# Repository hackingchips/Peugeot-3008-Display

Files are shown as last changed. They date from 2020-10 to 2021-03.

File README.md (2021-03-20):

## Repairing Peugeot 3008 display. ##

This repository is about changing the LCD crystal of my Peugeot 3008 multifunction display.

If you want more information go the following links:

* http://www.hackingchips.com/2020/09/reparacion-de-display-peugeot-3008.html
* http://www.hackingchips.com/2020/09/reparacion-de-display-peugeot-3008_22.html
* http://www.hackingchips.com/2020/09/reparacion-de-display-peugeot-3008_23.html
* http://www.hackingchips.com/2020/09/reparacion-de-display-peugeot-3008_25.html
* http://www.hackingchips.com/2020/09/reparacion-de-display-peugeot-3008_26.html
* http://www.hackingchips.com/2020/10/reparacion-de-display-peugeot-3008.html

### Repository. ###
* Docs: Datasheets and notes.
* Firmware/PeugeotDisplay4245: Firmware for Cypress PSoC CY8C4245 (PSoC Creator 4.3 project).
* Hardware/PeugeotTypeCDisplayHack: Kicad project (schematic & pcb board).
* Mechanical: 3D models.
* NewestArchives_xxx_date_xxx: Latest binary & docs.

#### Thanks to Peter Pinter ([morcibacsi]). His project PSAWifiDisplayControl (https://github.com/morcibacsi/PSAWifiDisplayControl) saved me a lot of work. ####

[morcibacsi]: https://github.com/morcibacsi

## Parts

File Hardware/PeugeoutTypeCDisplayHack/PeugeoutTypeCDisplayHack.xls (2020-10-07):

Source | C:\Users\Jesus\Desktop\display_coche\LCD_Substitute\Hardware\PeugeoutTypeCDisplayHack\PeugeoutTypeCDisplayHack.sch
Kicad Rev | Eeschema (5.1.6)-1
Generated Date | 24/09/2020 17:53:35
Title | Peugeot Type C Display Hack
Company | Hackingchips.com
Revision | 1
Date Issue | 2020-09-18
Comment | (C) Jesús Rodríguez Cacabelos
Reference | Value | Library | Library Ref
J3 | ER-CON30HB-1 | PeugeotTypeCDisplayHack | ER-CON30HB-1
C12 | 4u7 | PeugeotTypeCDisplayHack | CP_Small
C13 | 4u7 | PeugeotTypeCDisplayHack | CP_Small
C11 | 100nF | PeugeotTypeCDisplayHack | C_Small
C8 | 10uF | PeugeotTypeCDisplayHack | CP_Small
C9 | 100nF | PeugeotTypeCDisplayHack | C_Small
U2 | CY8C4245AXI-483 | PeugeotTypeCDisplayHack | CY8C4245AXI-483
C6 | 10nF | PeugeotTypeCDisplayHack | C
C7 | 100nF | PeugeotTypeCDisplayHack | C
C5 | 1uF/25 | PeugeotTypeCDisplayHack | C
C10 | 100nF | PeugeotTypeCDisplayHack | C_Small
R1 | 4K7 | PeugeotTypeCDisplayHack | R_US
R10 | 10M | PeugeotTypeCDisplayHack | R_US
C3 | 10uF | PeugeotTypeCDisplayHack | CP
C1 | 10uF | PeugeotTypeCDisplayHack | CP
C4 | 100nF | PeugeotTypeCDisplayHack | C
C2 | 100nf | PeugeotTypeCDisplayHack | C
R2 | 1K | PeugeotTypeCDisplayHack | R_US
R3 | 1K | PeugeotTypeCDisplayHack | R_US
R4 | 1K | PeugeotTypeCDisplayHack | R_US
R5 | 1K | PeugeotTypeCDisplayHack | R_US
R6 | 2K | PeugeotTypeCDisplayHack | R_US
R8 | 2K | PeugeotTypeCDisplayHack | R_US
R7 | 2K | PeugeotTypeCDisplayHack | R_US
R9 | 2K | PeugeotTypeCDisplayHack | R_US
J1 | PeugeotPCBConnector | PeugeotTypeCDisplayHack | PeugeotPCBConnector
U1 | LM1117-3.3 | PeugeotTypeCDisplayHack | LM1117-3.3
J2 | Conn_01x05 | PeugeotTypeCDisplayHack | Conn_01x05
J4 | Backlight | PeugeotTypeCDisplayHack | Conn_01x02
R11 | ??? | PeugeotTypeCDisplayHack | R_US
S2 | F.Use | PeugeotTypeCDisplayHack | Conn_01x02
S1 | F.Use | PeugeotTypeCDisplayHack | Conn_01x02

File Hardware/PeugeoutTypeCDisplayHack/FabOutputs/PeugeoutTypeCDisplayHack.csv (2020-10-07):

Id | Identificador | Empaquetado | Cantidad | Identificación | Suministrador y ref
1 | R11 | R_1206_3216Metric_Pad1.42x1.75mm_HandSolder | 1 | ???
2 | J4 | PinHeader_1x02_P2.00mm_Vertical | 1 | Backlight
3 | R1 | R_0805_2012Metric_Pad1.15x1.40mm_HandSolder | 1 | 4K7
4 | J2 | PinHeader_1x05_P1.27mm_Vertical | 1 | Conn_01x05
5 | R10 | R_0805_2012Metric_Pad1.15x1.40mm_HandSolder | 1 | 10M
6 | R9,R8,R7,R6 | R_0805_2012Metric_Pad1.15x1.40mm_HandSolder | 4 | 2K
7 | R5,R4,R3,R2 | R_0805_2012Metric_Pad1.15x1.40mm_HandSolder | 4 | 1K
8 | C13,C12 | C_0805_2012Metric_Pad1.15x1.40mm_HandSolder | 2 | 4u7
9 | C11,C10,C9,C7,C4 | C_0805_2012Metric_Pad1.15x1.40mm_HandSolder | 5 | 100nF
10 | C8,C3,C1 | C_0805_2012Metric_Pad1.15x1.40mm_HandSolder | 3 | 10uF
11 | C6 | C_0805_2012Metric_Pad1.15x1.40mm_HandSolder | 1 | 10nF
12 | C5 | C_0805_2012Metric_Pad1.15x1.40mm_HandSolder | 1 | 1uF/25
13 | C2 | C_0805_2012Metric_Pad1.15x1.40mm_HandSolder | 1 | 100nf
14 | U1 | SOT-223-3_TabPin2 | 1 | LM1117-3.3
15 | J1 | PeugeotPCBConnector | 1 | PeugeotPCBConnector
16 | U2 | TQFP-44_10x10mm_P0.8mm | 1 | CY8C4245AXI-483
17 | J3 | ER-CON30HB-1 | 1 | ER-CON30HB-1

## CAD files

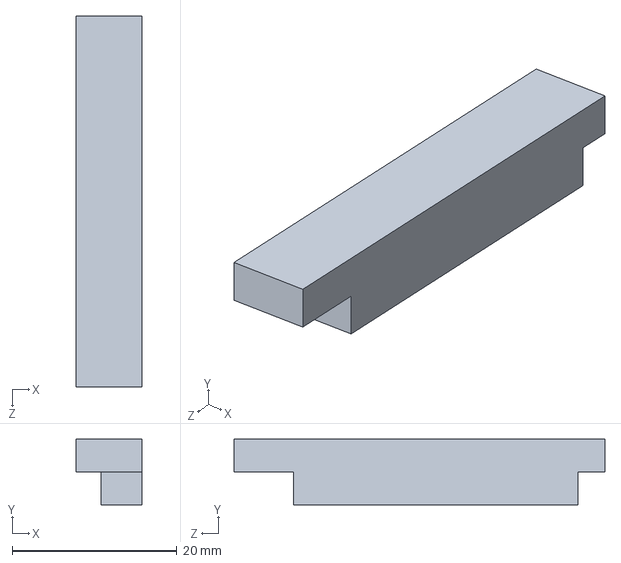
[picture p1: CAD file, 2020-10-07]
Mechanical/Sup_Left.SLDPRT
8.00 x 8.00 x 45.0 mm

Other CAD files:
Mechanical/Sup_Right.SLDPRT
Mechanical/Sup_Left.STL
Mechanical/Sup_Right.STL

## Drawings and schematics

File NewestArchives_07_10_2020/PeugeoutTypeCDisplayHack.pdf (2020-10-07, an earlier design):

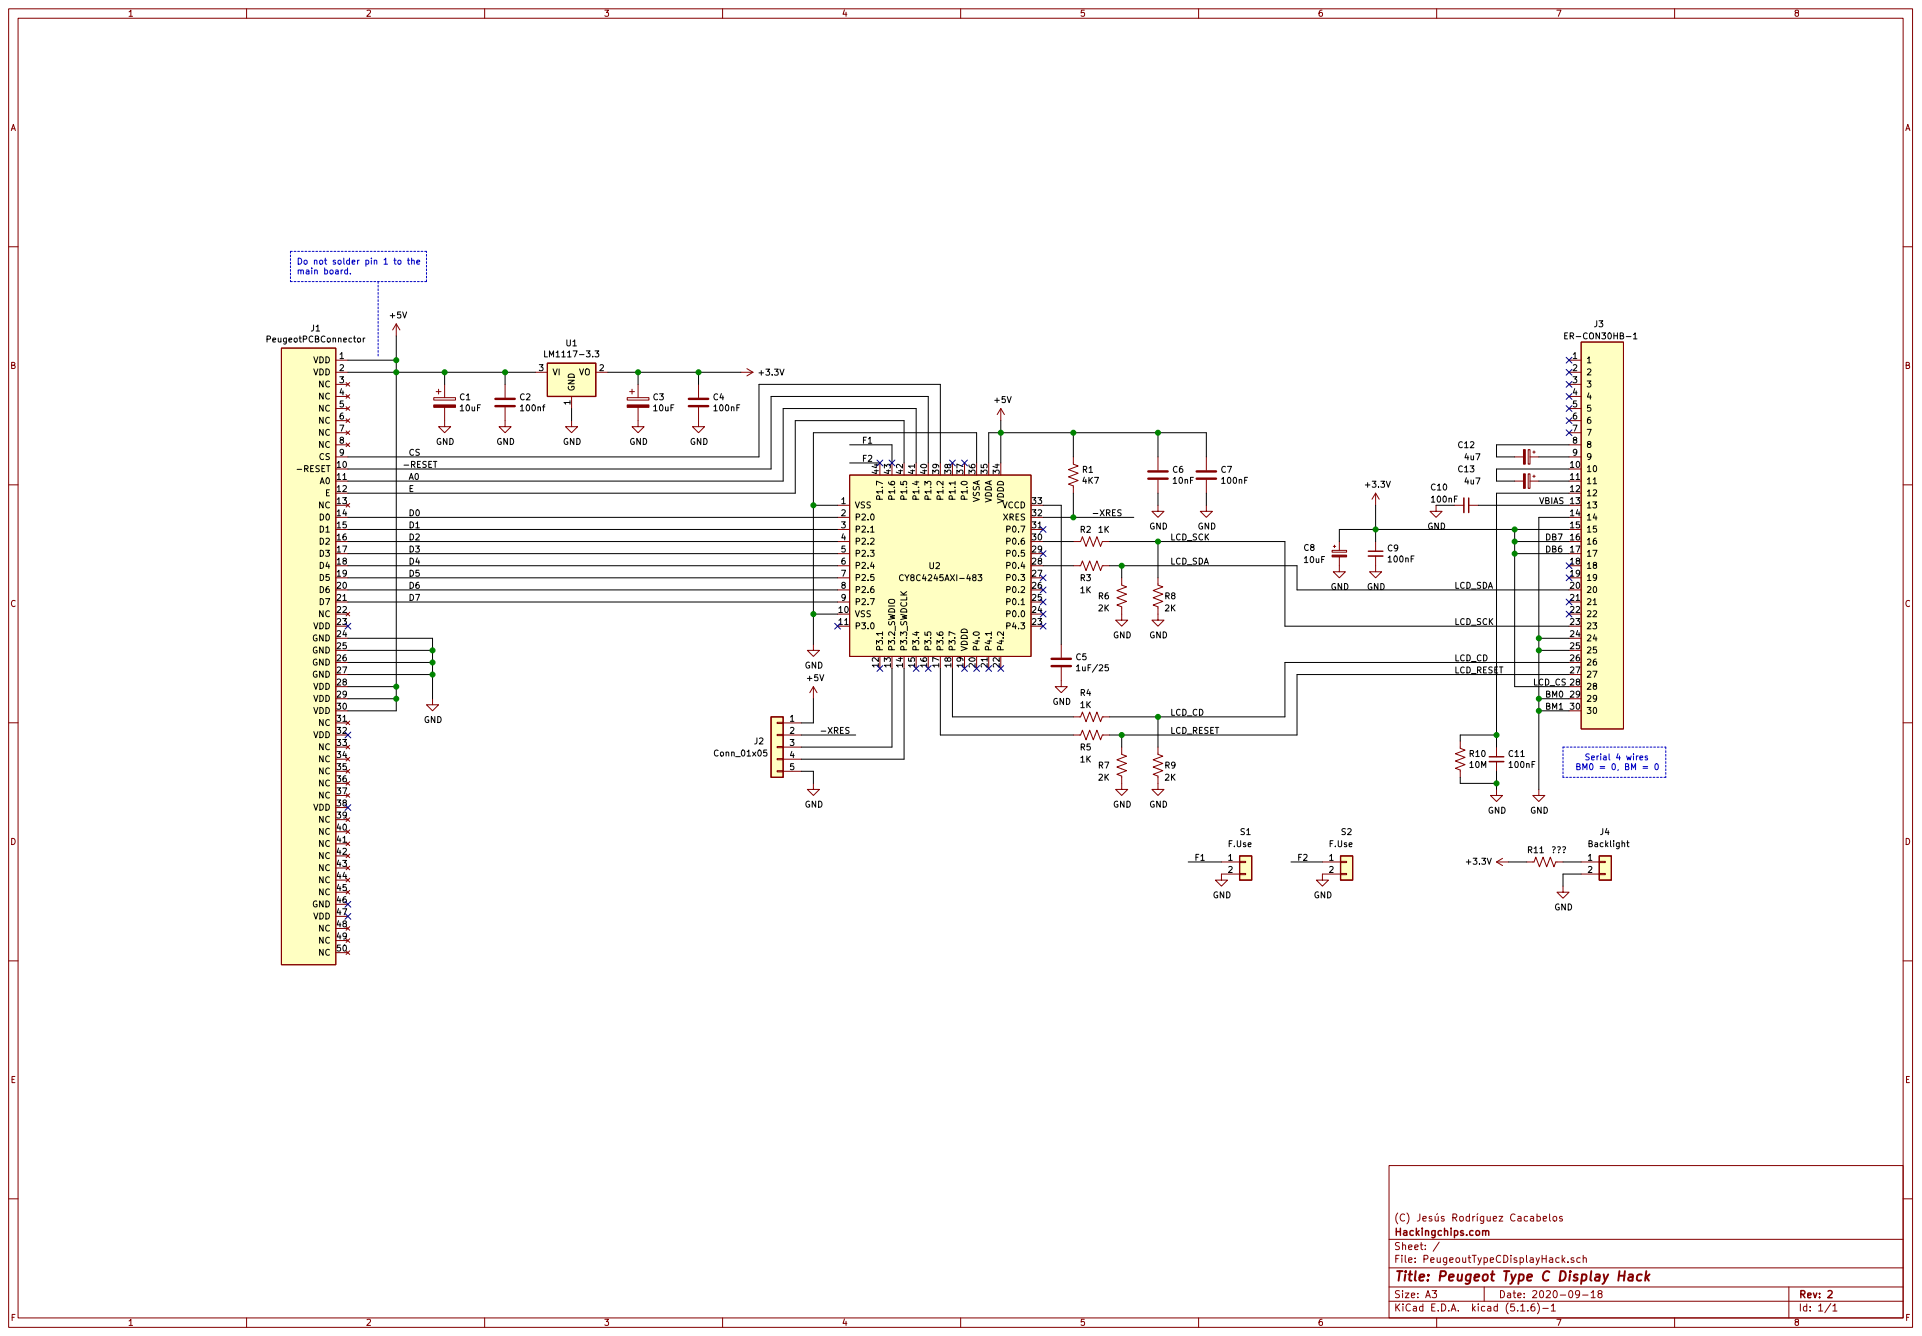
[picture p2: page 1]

A0ED1 Do not solder pin 1 to the main board.

LCD_RESET

LCD_CS

(C) Jesús Rodríguez Cacabelos
File: PeugeoutTypeCDisplayHack.sch Sheet: / Hackingchips.com

Id: 1/1 Title: Peugeot Type C Display Hack

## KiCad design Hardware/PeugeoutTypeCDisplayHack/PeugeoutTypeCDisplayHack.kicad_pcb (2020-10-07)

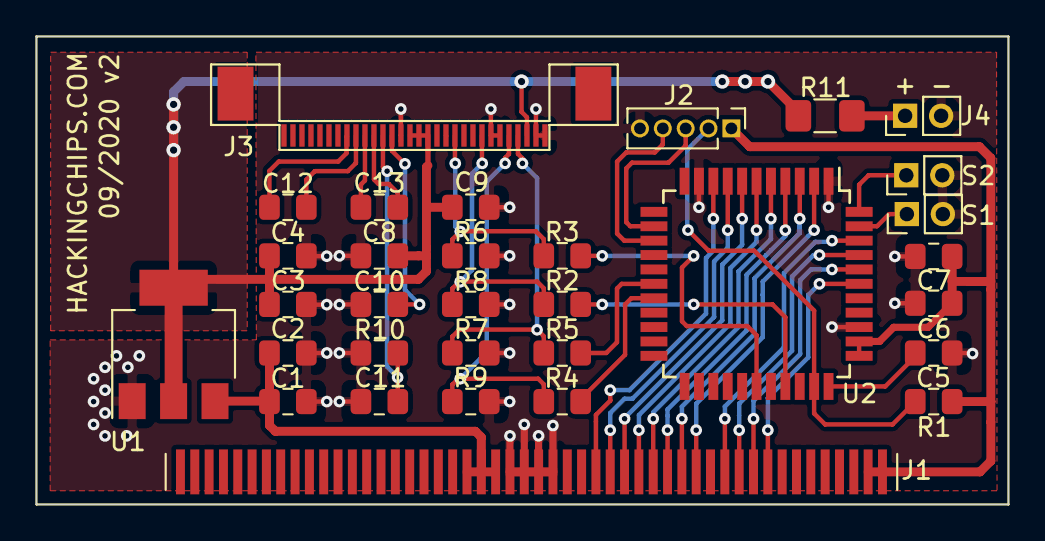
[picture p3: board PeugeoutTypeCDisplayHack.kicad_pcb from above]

Board: 2 copper layers, 54.0 x 26.0 mm, 32 parts (0 on the bottom side), 36 nets.

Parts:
C1, C3, C8: 10uF; C_0805_2012Metric_Pad1.15x1.40mm_HandSolder
C2: 100nf; C_0805_2012Metric_Pad1.15x1.40mm_HandSolder
C4, C7, C9, C10, C11: 100nF; C_0805_2012Metric_Pad1.15x1.40mm_HandSolder
C5: 1uF/25; C_0805_2012Metric_Pad1.15x1.40mm_HandSolder
C6: 10nF; C_0805_2012Metric_Pad1.15x1.40mm_HandSolder
C12, C13: 4u7; C_0805_2012Metric_Pad1.15x1.40mm_HandSolder
J1: PeugeotPCBConnector
J2: Conn_01x05; PinHeader_1x05_P1.27mm_Vertical
J3: ER-CON30HB-1
J4: Backlight; PinHeader_1x02_P2.00mm_Vertical
R1: 4K7; R_0805_2012Metric_Pad1.15x1.40mm_HandSolder
R2, R3, R4, R5: 1K; R_0805_2012Metric_Pad1.15x1.40mm_HandSolder
R6, R7, R8, R9: 2K; R_0805_2012Metric_Pad1.15x1.40mm_HandSolder
R10: 10M; R_0805_2012Metric_Pad1.15x1.40mm_HandSolder
R11: ???; R_1206_3216Metric_Pad1.42x1.75mm_HandSolder
S1, S2: F.Use; PinHeader_1x02_P2.00mm_Vertical
U1: LM1117-3.3; SOT-223-3_TabPin2
U2: CY8C4245AXI-483; TQFP-44_10x10mm_P0.8mm

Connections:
+3V3: C3.1, C4.1, C8.1, C9.1, J3.15, J3.16, J3.17, J3.28, R11.2, U1.2
+5V: C1.1, C2.1, C6.1, C7.1, J1.1, J1.2, J1.28, J1.29, J1.30, J2.1, R1.1, U1.3, U2.34, U2.35
/-RESET: J1.10, U2.40
/-XRES: J2.2, R1.2, U2.32
/A0: J1.11, U2.41
/CS: J1.9, U2.39
/D0: J1.14, U2.2
/D1: J1.15, U2.3
/D2: J1.16, U2.4
/D3: J1.17, U2.5
/D4: J1.18, U2.6
/D5: J1.19, U2.7
/D6: J1.20, U2.8
/D7: J1.21, U2.9
/E: J1.12, U2.42
/F1: S1.1, U2.43
/F2: S2.1, U2.44
/LCD_CD: J3.26, R4.1, R9.1
/LCD_RESET: J3.27, R5.1, R7.1
/LCD_SCK: J3.23, R2.1, R8.1
/LCD_SDA: J3.20, R3.1, R6.1
/VBIAS: C10.1, J3.13
GND: C1.2, C2.2, C3.2, C4.2, C5.2, C6.2, C7.2, C8.2, C9.2, C10.2, C11.2, J1.24, J1.25, J1.26, J1.27, J2.5, J3.14, J3.24, J3.25, J3.29, J3.30, J4.2, R6.2, R7.2, R8.2, R9.2, R10.2, S1.2, S2.2, U1.1, U2.1, U2.10, U2.36
unnamed: C5.1, U2.33
unnamed: C11.1, J3.12, R10.1
unnamed: C12.1, J3.9
unnamed: C12.2, J3.8
unnamed: C13.1, J3.11
unnamed: C13.2, J3.10
unnamed: J2.3, U2.13
unnamed: J2.4, U2.14
unnamed: J4.1, R11.1
unnamed: R2.2, U2.30
unnamed: R3.2, U2.28
unnamed: R4.2, U2.18
unnamed: R5.2, U2.17

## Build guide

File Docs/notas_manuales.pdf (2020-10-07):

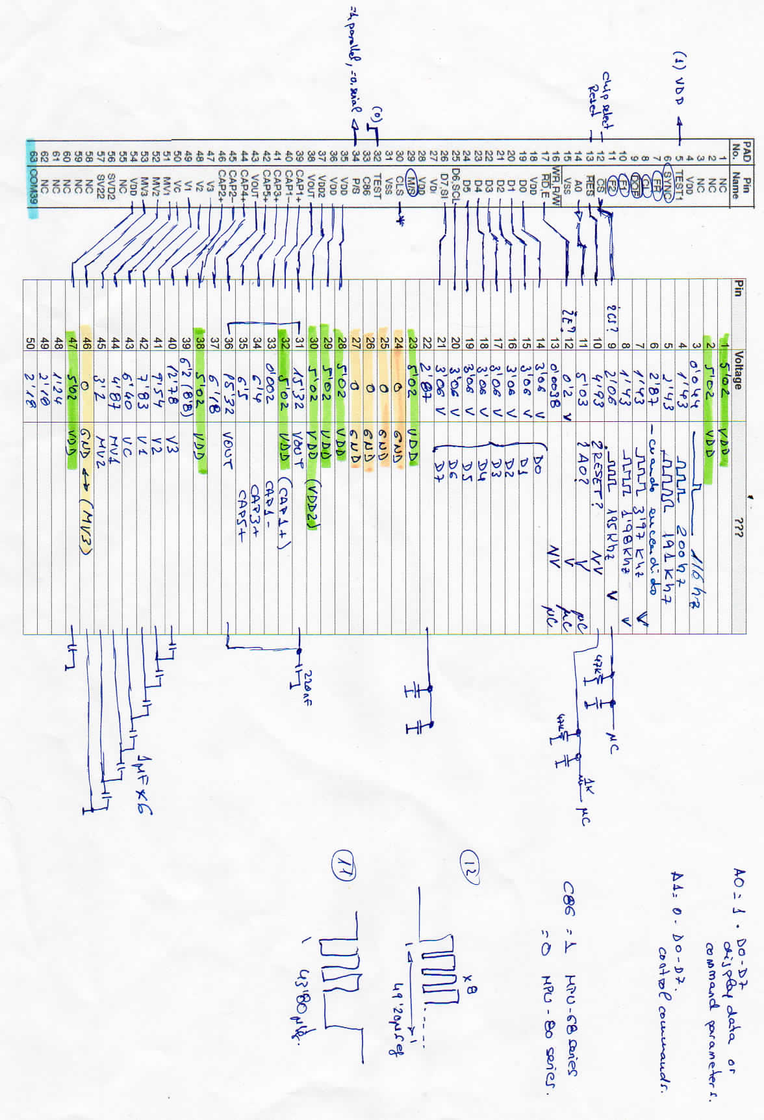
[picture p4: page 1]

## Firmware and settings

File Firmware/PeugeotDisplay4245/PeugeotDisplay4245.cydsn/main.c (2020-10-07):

/* ========================================
 *
 * Copyright YOUR COMPANY, THE YEAR
 * All Rights Reserved
 * UNPUBLISHED, LICENSED SOFTWARE.
 *
 * CONFIDENTIAL AND PROPRIETARY INFORMATION
 * WHICH IS THE PROPERTY OF your company.
 *
 * ========================================
*/
#include "project.h"
#include "UC1608.h"

//#define SERIAL_PORT_SEND_DATA
#define SERIAL_PORT_SEND_PROCCESSED

/* ************************************************************************* */
enum { IDLE, DATA0, DATA1, DATA2 } BUS_STATE;

volatile    uint8 bus_state = IDLE;

volatile    uint8 data_buffer[2000];
volatile    uint16 data_buffer_ptr = 0;

volatile    uint8 data_ready = 0;

volatile    uint8 enable_capture = 0;

volatile    uint8 combined_data = 0;
volatile    uint8 page_counter = 0;
volatile    uint8 column_counter = 0;
volatile    uint8 is_first_byte = 1;

volatile    uint8 display_set_normal = 0;
volatile    uint8 display_set_reverse = 0;

/* Interrupt prototypes */
CY_ISR_PROTO(ISR_Reset_Handler);
CY_ISR_PROTO(ISR_Capture);

void Uart_SendCommandString(uint8 command);

/* ************************************************************************* */


/* Manage interrupt from RESET. */
CY_ISR(ISR_Reset_Handler)
{
}

/* Manage interrupt for command capture. */
CY_ISR(ISR_Capture_Handler)
{
    uint8 a0_state = A0_Read();
    uint8 e_state = E_Read();
    
    uint8 bdata = IData_Port_Read();
    
    /* *** Waiting for command "data write". *** */
    if (bus_state == IDLE)
    {
        if ((e_state == 1) && (a0_state == 0))
        {
            if (bdata == 0b00011101)                                            // 0b00011101 = Display data write command.
            {
                page_counter = column_counter = data_buffer_ptr = 0;            // Initialize counters and buffer pointer.
                bus_state = DATA0;
            }
            
            if (bdata == 0b10100110) display_set_normal = 1;                    // Display normal.
            if (bdata == 0b10100111) display_set_reverse = 1;                   // Display reverse.
        }
    }
    /* *** First byte received is a dummy byte. We discard it. *** */
    else if (bus_state == DATA0) 
    {
        bus_state = DATA1;
    }
    /* *** Received even page byte. *** */
    else if (bus_state == DATA1)
    {

        if ((e_state == 0) && (a0_state == 1))
        {
            if ((page_counter < 16) && (column_counter < 240))                  // Data outside display is discarded.
            {
                combined_data = (bdata & 0b00000001) |                          // Isolate every low bit of every pixel and move them to the 
                                ((bdata & 0b00000100) >> 1) |                   // lower nibble of the final data byte.
                                ((bdata & 0b00010000) >> 2) |
                                ((bdata & 0b01000000) >> 3);
                                
                bus_state = DATA2;
            }
                            
            page_counter++;
            if (page_counter == 21) 
            {
                page_counter = 0; 
                column_counter++;
            }
        }
        else if ( e_state == 1 )
        {
            data_ready = 1;
            bus_state = IDLE;
            CyGlobalIntDisable;
        }

    }
    /* *** Received odd page byte. *** */
    else if (bus_state == DATA2)
    {
        if ((e_state == 0) && (a0_state == 1))
        {
            if ((page_counter < 16) && (column_counter < 240))                  // Data outside display is discarded.
            {
                combined_data = combined_data | ((bdata & 0b00000001) << 4) |   // Isolate every low bit of every pixel and move them to the
                                                ((bdata & 0b00000100) << 3) |   // higher nibble of the final data byte.
                                                ((bdata & 0b00010000) << 2) |   // Combine it with the previous lower nibble.
                                                ((bdata & 0b01000000) << 1);
                                                
                bus_state = DATA1;
                                                
                data_buffer[data_buffer_ptr] = combined_data;
                data_buffer_ptr++;
            }
                                            
            page_counter++;
            if (page_counter == 21) 
            {
                page_counter = 0; 
                column_counter++;
            }                                             
        }
        else if ( e_state == 1 )                                                
        {
            data_ready = 1;                                                     // All data has been received, converted to 1 byte 
            bus_state = IDLE;                                                   // monocrome and stored in buffer.
            CyGlobalIntDisable;                                                 // Set data_ready flag and disable interrupts.
        }
    }    
}

/* ************************************************************************* */

int main(void)
{
    uint8 page, column;
    
    /* Configure and enable interrupts. */
    ISR_Reset_StartEx(ISR_Reset_Handler);
    ISR_Capture_StartEx(ISR_Capture_Handler);
    //CyGlobalIntEnable;
    
    /* Init SPILCD. */
    SPILCD_Start();
    
    /* Initialize the display. */
    LCD_Init();
    LCD_Clear();     
          
    LCD_SetPageAddress(0);
    LCD_SetColumnAddress(0);    
    
    enable_capture = 1;
    CyGlobalIntEnable;    

    for(;;)
    {
  
        /* --------------------------------------------- */
        
        if (data_ready == 1)
        {
            LCD_SetPageAddress(0);
            LCD_SetColumnAddress(0);
        
            for (page = 0; page < 8; page++)
            {    
                for (column = 0; column < 240; column++)
                {
                
                    UC1608_Write_data(data_buffer[(column * 8) + page]);
                }
            }            
            
            if (enable_capture) CyGlobalIntEnable;
        }
        
        if (display_set_normal)
        {
            LCD_DisplayNormal();
            display_set_normal = 0;
        }
        
        if (display_set_reverse)
        {
            LCD_DisplayReverse();
            display_set_reverse = 0;
        }
    
        
    }
}

/* [] END OF FILE */

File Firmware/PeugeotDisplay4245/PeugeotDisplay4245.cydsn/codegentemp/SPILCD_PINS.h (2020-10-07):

/***************************************************************************//**
* \file SPILCD_PINS.h
* \version 4.0
*
* \brief
*  This file provides constants and parameter values for the pin components
*  buried into SCB Component.
*
* Note:
*
********************************************************************************
* \copyright
* Copyright 2013-2017, Cypress Semiconductor Corporation.  All rights reserved.
* You may use this file only in accordance with the license, terms, conditions,
* disclaimers, and limitations in the end user license agreement accompanying
* the software package with which this file was provided.
*******************************************************************************/

#if !defined(CY_SCB_PINS_SPILCD_H)
#define CY_SCB_PINS_SPILCD_H

#include "cydevice_trm.h"
#include "cyfitter.h"
#include "cytypes.h"


/***************************************
*   Conditional Compilation Parameters
****************************************/

/* Unconfigured pins */
#define SPILCD_REMOVE_RX_WAKE_SCL_MOSI_PIN  (1u)
#define SPILCD_REMOVE_RX_SCL_MOSI_PIN      (1u)
#define SPILCD_REMOVE_TX_SDA_MISO_PIN      (1u)
#define SPILCD_REMOVE_SCLK_PIN      (1u)
#define SPILCD_REMOVE_SS0_PIN      (1u)
#define SPILCD_REMOVE_SS1_PIN                 (1u)
#define SPILCD_REMOVE_SS2_PIN                 (1u)
#define SPILCD_REMOVE_SS3_PIN                 (1u)

/* Mode defined pins */
#define SPILCD_REMOVE_I2C_PINS                (1u)
#define SPILCD_REMOVE_SPI_MASTER_PINS         (0u)
#define SPILCD_REMOVE_SPI_MASTER_SCLK_PIN     (0u)
#define SPILCD_REMOVE_SPI_MASTER_MOSI_PIN     (0u)
#define SPILCD_REMOVE_SPI_MASTER_MISO_PIN     (1u)
#define SPILCD_REMOVE_SPI_MASTER_SS0_PIN      (1u)
#define SPILCD_REMOVE_SPI_MASTER_SS1_PIN      (1u)
#define SPILCD_REMOVE_SPI_MASTER_SS2_PIN      (1u)
#define SPILCD_REMOVE_SPI_MASTER_SS3_PIN      (1u)
#define SPILCD_REMOVE_SPI_SLAVE_PINS          (1u)
#define SPILCD_REMOVE_SPI_SLAVE_MOSI_PIN      (1u)
#define SPILCD_REMOVE_SPI_SLAVE_MISO_PIN      (1u)
#define SPILCD_REMOVE_UART_TX_PIN             (1u)
#define SPILCD_REMOVE_UART_RX_TX_PIN          (1u)
#define SPILCD_REMOVE_UART_RX_PIN             (1u)
#define SPILCD_REMOVE_UART_RX_WAKE_PIN        (1u)
#define SPILCD_REMOVE_UART_RTS_PIN            (1u)
#define SPILCD_REMOVE_UART_CTS_PIN            (1u)

/* Unconfigured pins */
#define SPILCD_RX_WAKE_SCL_MOSI_PIN (0u == SPILCD_REMOVE_RX_WAKE_SCL_MOSI_PIN)
#define SPILCD_RX_SCL_MOSI_PIN     (0u == SPILCD_REMOVE_RX_SCL_MOSI_PIN)
#define SPILCD_TX_SDA_MISO_PIN     (0u == SPILCD_REMOVE_TX_SDA_MISO_PIN)
#define SPILCD_SCLK_PIN     (0u == SPILCD_REMOVE_SCLK_PIN)
#define SPILCD_SS0_PIN     (0u == SPILCD_REMOVE_SS0_PIN)
#define SPILCD_SS1_PIN                (0u == SPILCD_REMOVE_SS1_PIN)
#define SPILCD_SS2_PIN                (0u == SPILCD_REMOVE_SS2_PIN)
#define SPILCD_SS3_PIN                (0u == SPILCD_REMOVE_SS3_PIN)

/* Mode defined pins */
#define SPILCD_I2C_PINS               (0u == SPILCD_REMOVE_I2C_PINS)
#define SPILCD_SPI_MASTER_PINS        (0u == SPILCD_REMOVE_SPI_MASTER_PINS)
#define SPILCD_SPI_MASTER_SCLK_PIN    (0u == SPILCD_REMOVE_SPI_MASTER_SCLK_PIN)
#define SPILCD_SPI_MASTER_MOSI_PIN    (0u == SPILCD_REMOVE_SPI_MASTER_MOSI_PIN)
#define SPILCD_SPI_MASTER_MISO_PIN    (0u == SPILCD_REMOVE_SPI_MASTER_MISO_PIN)
#define SPILCD_SPI_MASTER_SS0_PIN     (0u == SPILCD_REMOVE_SPI_MASTER_SS0_PIN)
#define SPILCD_SPI_MASTER_SS1_PIN     (0u == SPILCD_REMOVE_SPI_MASTER_SS1_PIN)
#define SPILCD_SPI_MASTER_SS2_PIN     (0u == SPILCD_REMOVE_SPI_MASTER_SS2_PIN)
#define SPILCD_SPI_MASTER_SS3_PIN     (0u == SPILCD_REMOVE_SPI_MASTER_SS3_PIN)
#define SPILCD_SPI_SLAVE_PINS         (0u == SPILCD_REMOVE_SPI_SLAVE_PINS)
#define SPILCD_SPI_SLAVE_MOSI_PIN     (0u == SPILCD_REMOVE_SPI_SLAVE_MOSI_PIN)
#define SPILCD_SPI_SLAVE_MISO_PIN     (0u == SPILCD_REMOVE_SPI_SLAVE_MISO_PIN)
#define SPILCD_UART_TX_PIN            (0u == SPILCD_REMOVE_UART_TX_PIN)
#define SPILCD_UART_RX_TX_PIN         (0u == SPILCD_REMOVE_UART_RX_TX_PIN)
#define SPILCD_UART_RX_PIN            (0u == SPILCD_REMOVE_UART_RX_PIN)
#define SPILCD_UART_RX_WAKE_PIN       (0u == SPILCD_REMOVE_UART_RX_WAKE_PIN)
#define SPILCD_UART_RTS_PIN           (0u == SPILCD_REMOVE_UART_RTS_PIN)
#define SPILCD_UART_CTS_PIN           (0u == SPILCD_REMOVE_UART_CTS_PIN)


/***************************************
*             Includes
****************************************/

#if (SPILCD_RX_WAKE_SCL_MOSI_PIN)
    #include "SPILCD_uart_rx_wake_i2c_scl_spi_mosi.h"
#endif /* (SPILCD_RX_SCL_MOSI) */

#if (SPILCD_RX_SCL_MOSI_PIN)
    #include "SPILCD_uart_rx_i2c_scl_spi_mosi.h"
#endif /* (SPILCD_RX_SCL_MOSI) */

#if (SPILCD_TX_SDA_MISO_PIN)
    #include "SPILCD_uart_tx_i2c_sda_spi_miso.h"
#endif /* (SPILCD_TX_SDA_MISO) */

#if (SPILCD_SCLK_PIN)
    #include "SPILCD_spi_sclk.h"
#endif /* (SPILCD_SCLK) */

#if (SPILCD_SS0_PIN)
    #include "SPILCD_spi_ss0.h"
#endif /* (SPILCD_SS0_PIN) */
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
